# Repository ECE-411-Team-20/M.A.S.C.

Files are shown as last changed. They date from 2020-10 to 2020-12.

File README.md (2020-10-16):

# Project M.A.S.C.
Practicum Project

Mask to Actively Shield from COVID (M.A.S.C.)

A face shield of some type (either head or collar mounted) that exposes the face by default, but should the wearer start to walk, or should someone approach the user, the face shield moves to cover the wearer's face

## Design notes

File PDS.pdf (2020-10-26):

Welsh Jehnoy, Genther Derrick, Huynh Khoa, Arch Ryan, Yogi Saputra Team 20
ECE 411
10/25/2020
Homework 2 PDS

Executive Summary / Concept of Operations
Mask to Actively Shield from COVID (M.A.S.C.)
The MASC is an automated COVID facemask to optimize the users mask experience during COVID, and future, pandemics. Using cutting edge technology, this smart mask is capable to determining when the wearer is at the most risk of exposure to other persons due to proximity and automatically moves a barrier over the wearers face. When the risk has been determined to be mitigated by sufficient distance, the mask moves away from the wearers face.
As an additional precaution to protect the user in a chaotic world, the mask defaults to a closed position when the user walks for more than a few steps so that acute exposure can be prevented by quick moving persons during motion.

Brief Market Analysis
The MASC is designed to attract customers who want to only wear a mask when needed to avoid exposure to covid-19, or other airborne diseases. Certain persons such as nurses, and doctors will also be an intended target audience for the product as they will need it to make sure that they have worn a mask at the times when needed.
The competition is any products that help prevent exposure to covid-19. In particular, and the most common competition is any mask products as they are the most common item used to avoid exposure to covid-19 and other airborne illness. The mask product that will be produced has it’s advantage of automatically closing and opening based on it’s detection of possible airborne diseases nearby. This advantage will be used to take consumers who dislike wearing a mask when it’s not necessary to do so.
The price for this product will depend on the price of the parts needed to create the product. A strong price to keep the product competitive is $20. This will ensure that customers won’t be lured away from purchasing the product because of a large price tag, and it’ll be cheap enough to make a decent profit.

Requirements
The mask must be able to detect when it needs to close to prevent the user contracting any airborne diseases. The mask will be able to detect it based on the distance of the user to another human, in which the mask will close upon close proximity to someone else. The mask must close when the user is walking. The mask must open when nobody is near them. The mask must be a portable device that can fit on the user’s face. The mask must be as lightweight as possible and comfortable on the wearer’s head. The mask must allow the user to breathe.

System Architecture

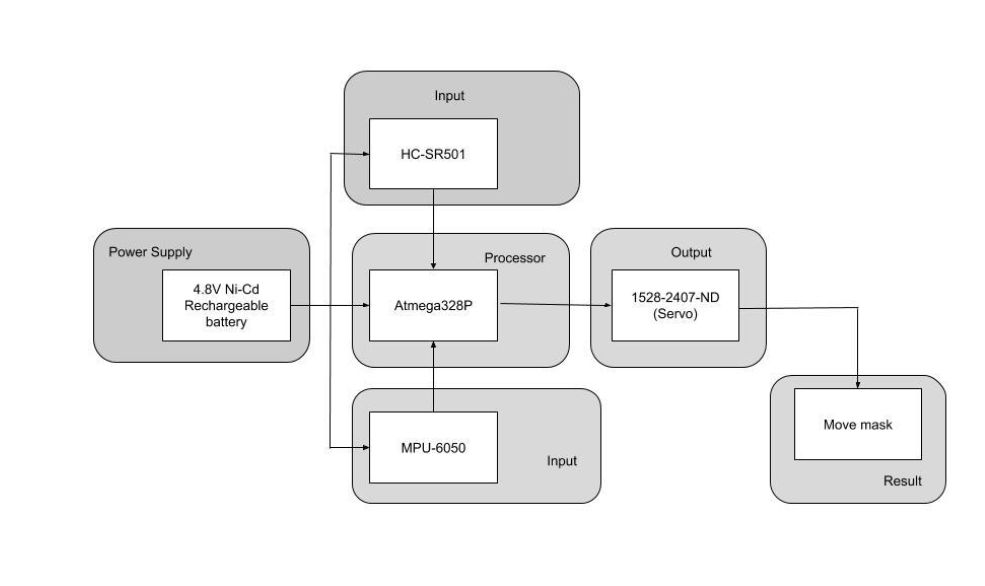
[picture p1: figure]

Design Specification
The unit will operate off of a Atmega328P that has been pre-loaded with the Arduino bootloader, which will be the IDE in the development.
This controller will utilize passive infrared detectors (HC-SR501) to tell if a person moves into proximity of the unit and an accelerometer (MPU-6050) to determine whether or not the wearer is in motion.
The sensors and microcontroller will be powered through a single 4.8V Ni-Cd rechargeable battery bank.
The motion of the shield itself is done through a continuous rotation servo (Adafruit PRODUCT ID: 3614) that is controlled via pulse-width modulation from the Atmega328P through an H-bridge circuit to be powered through a multi-cell battery pack (AA or C).
Prototyping will be done to determine the best means of motion for the mask. Types under consideration:
O Split mask than opens/closes in both directions
O Above-the-head mask that lowers/rises

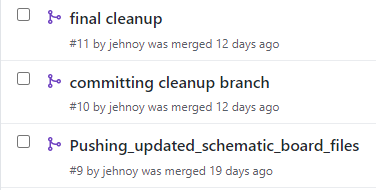
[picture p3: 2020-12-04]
final_commit_screenshots/Capture_commit.PNG

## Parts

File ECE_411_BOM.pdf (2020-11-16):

Bill of Materials for: Team 20 Last Modified: 11/12/2020
PCB version: design_v2
BOM revision: 1
Cnt | Parts | P/NP | Mfg | Mfg PN | Description | Dist | Dist Part Number | Cost Ea | Cost Total
1 | U1 | P | Atmel | ATMEGA328P-PU | 8-bit Microcontrollers - MCU 32KB In-system Flash 20MHz 1.8V-5.5V | Mouser | 556-ATMEGA328P-PU | $2.08 | $2.08
1 | Y1 | P | TXC Corp | 9B-16.000MEEJ-B | Crystals 16.000MHz 10ppm -20 +70C 18pF | Mouser | 717-9B-16.000MEEJ-B | $0.48 | $0.48
1 | J4 | P | Sparkfun | PRT-12748 | SparkFun Accessories DC Barrel Power Jack Connector SMD | Mouser | 474-PRT-12748 | $1.50 | $1.50
1 | IC1 | P | STMicroelectronics | LM317T | Linear Voltage Regulators 1.2-37V Adj Positive 1.5 Amp Output | Mouser | 511-LM317T | $0.64 | $0.64
2 | C7, C8 | P | TDK | C2012X5R1V106K0 85AC | Multilayer Ceramic Capacitors MLCC -SMD/SMT RECOMMENDED ALT 810-C2012X5R1V106K1C | Mouser | 810-C2012X5R1V106 K0C | $0.38 | $0.76
2 | C1, C2 | P | KEMET | C0805C220G5GAC TU | Multilayer Ceramic Capacitors MLCC -SMD/SMT 50V 22pF C0G 0805 0.02 | Mouser | 80-C0805C220G5G | $0.42 | $0.84
1 | C3 | P | KEMET | C0805X104M5RAC TU | Multilayer Ceramic Capacitors MLCC -SMD/SMT 50V 0.1uF X7R 0805 20% | Mouser | 80-C0805X104M5RAC TU | $0.52 | $0.52
1 | R2 | P | ROHM | SFR10EZPJ103 | Thick Film Resistors - SMD 10Kohm 0805 5% | Mouser | 755-SFR10EZPJ103 | $0.11 | $0.11
1 | S1 | P | C&K | PTS645SK50JSMT R92 LFS | Tactile Switches 50mA 12VDC, SPST NO, 260 gf, 5.0mm H, SMT J-type | Mouser | 611-SK50JSMTR92LF S | $0.41 | $0.41
1 | J1 | P | Adafruit | 1465 | ADAPTER MINI KIT BB AVR ISP 6PIN | Digi-Key | 1528-1189-ND | $0.95 | $0.95
1 | J2 | P | Wurth Electronik | 61300611121 | CONN HEADER VERT 6POS 2.54MM | Digi-Key | 732-5319-ND | $0.33 | $0.33

1 | M1 | N/P | Sparkfun | ROB-12625 | SparkFun Accessories Servo - Hitec HS-755HB (1/4 Scale) | Mouser | 474-ROB-12625 | $39.94 | $39.94
1 | U4 | N/P | MCM | 287-18001 | PIR motion detector module | Newark | 25AC5060 | $2.99 | $2.99
Total: | | | | | | | | $51.55

VERSION INFO

Rev | Date | Notes
1.0 | 2020-11-12 | Initial BOM.

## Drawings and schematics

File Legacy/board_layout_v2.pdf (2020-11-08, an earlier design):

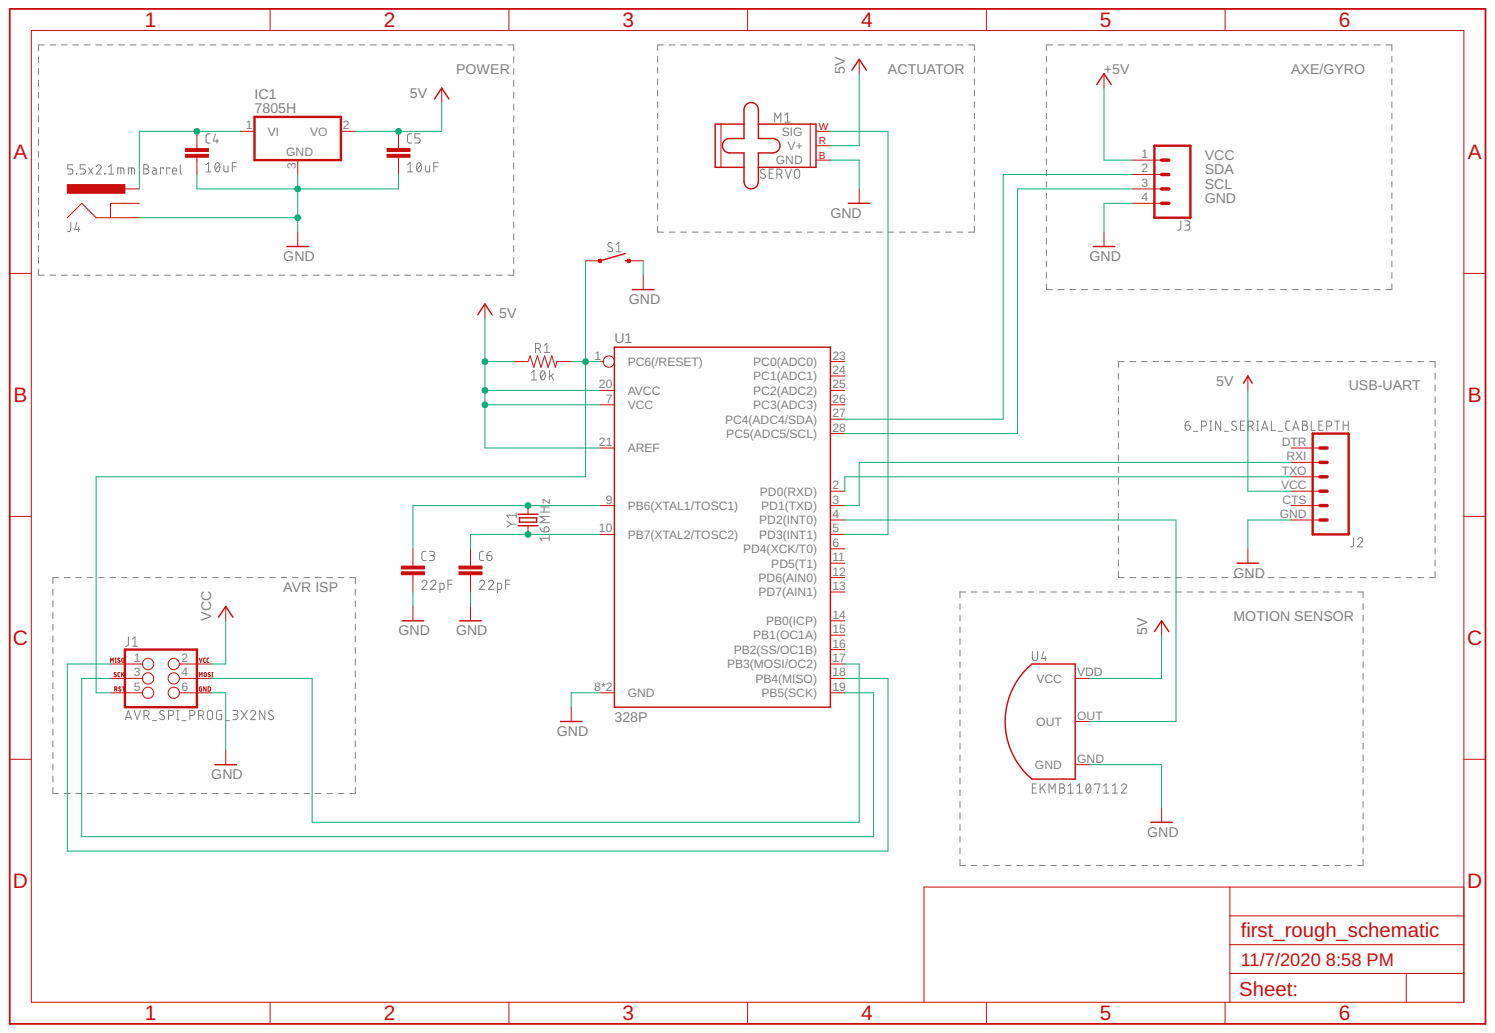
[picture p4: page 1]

3 4
5 6

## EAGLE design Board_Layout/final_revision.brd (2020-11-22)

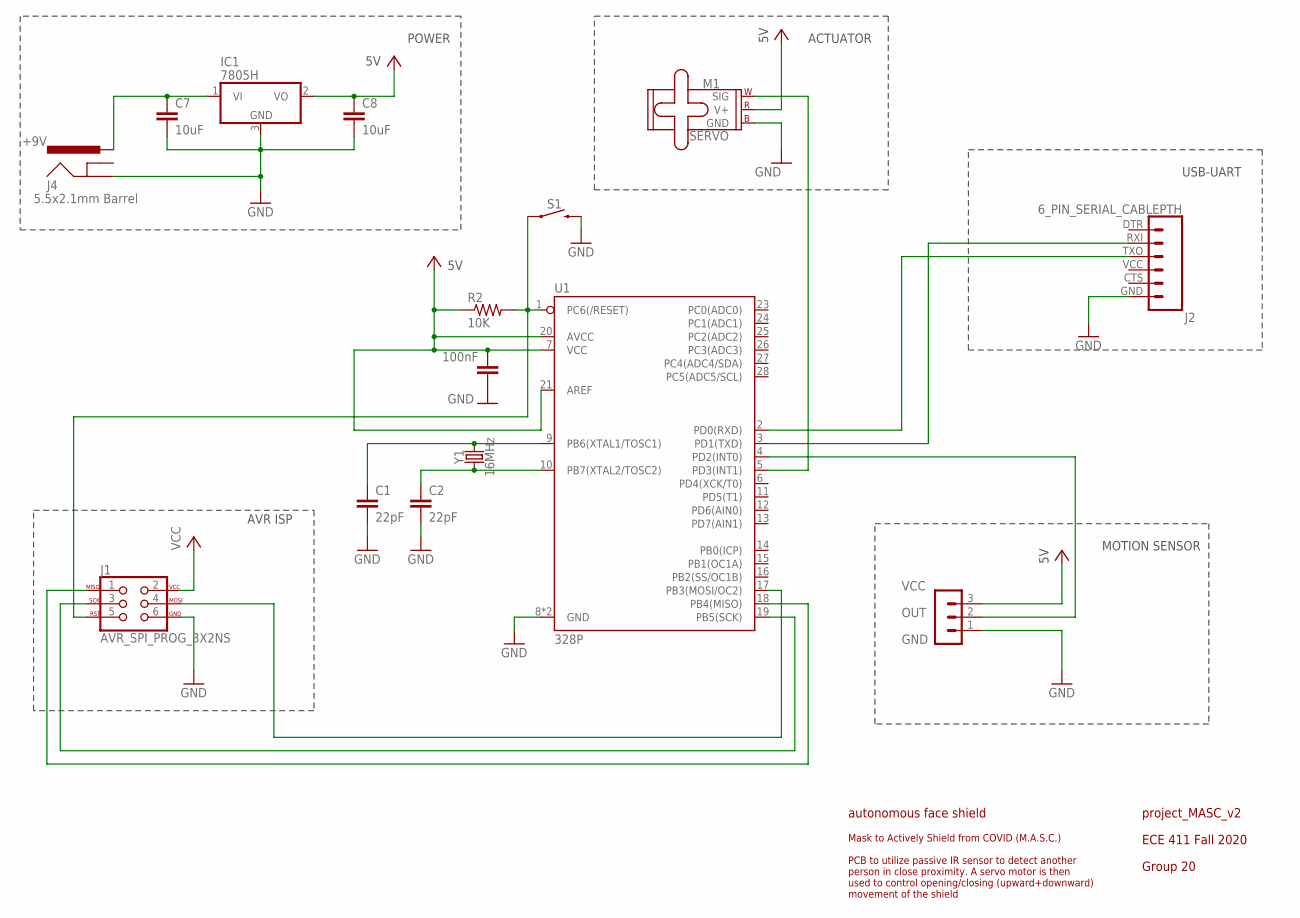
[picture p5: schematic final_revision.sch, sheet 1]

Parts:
C1, C2: 22pF; 0805
C3: 100nF; 0805
C7, C8: 10uF; 0805
IC1: 7805H; TO39
J1: AVR_SPI_PROG_3X2NS; 2X3-NS
J2: 6_PIN_SERIAL_CABLEPTH; FTDI_BASIC
J4: 5.5x2.1mm Barrel; POWER_JACK_SMD
M1: SERVO; 1X03
R2: 10K; R0805
S1: MOMENTARY-SWITCH-SPST-PTH-6.0MM; TACTILE_SWITCH_PTH_6.0MM
SV1: MA03-1
U1: 328P; DIP28
Y1: 16MHz; HC49US

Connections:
GND: C1.2, C2.2, C3.1, C7.2, C8.2, IC1.3 (GND), J1.6, J2.GND (6), J4.P$4 (GND), M1.3 (GND), S1.3 (2), SV1.1, U1.8 (GND), U1.22 (GND)
unnamed: J1.5, R2.2, S1.1, U1.1 (PC6(/RESET))
unnamed: J2.TXO (3), U1.2 (PD0(RXD))
unnamed: J2.RXI (2), U1.3 (PD1(TXD))
unnamed: C1.1, U1.9 (PB6(XTAL1/TOSC1)), Y1.2
unnamed: C2.1, U1.10 (PB7(XTAL2/TOSC2)), Y1.1
unnamed: C7.1, IC1.1 (VI), J4.VIN0 (PWR)
unnamed: SV1.2, U1.4 (PD2(INT0))
unnamed: M1.1 (SIG), U1.5 (PD3(INT1))
unnamed: J1.3, U1.19 (PB5(SCK))
unnamed: J1.1, U1.18 (PB4(MISO))
unnamed: J1.4, U1.17 (PB3(MOSI/OC2))
VCC: C3.2, C8.1, IC1.2 (VO), J1.2, M1.2 (V+), R2.1, SV1.3, U1.7 (VCC), U1.20 (AVCC), U1.21 (AREF)

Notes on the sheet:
POWER
ACTUATOR
MOTION SENSOR
USB-UART
AVR ISP
project_MASC_v2
autonomous face shield
Mask to Actively Shield from COVID (M.A.S.C.) PCB to utilize passive IR sensor to detect another person in close proximity. A servo motor is then used to control opening/closing (upward+downward) movement of the shield
Group 20
ECE 411 Fall 2020
+9V
VCC
OUT
GND

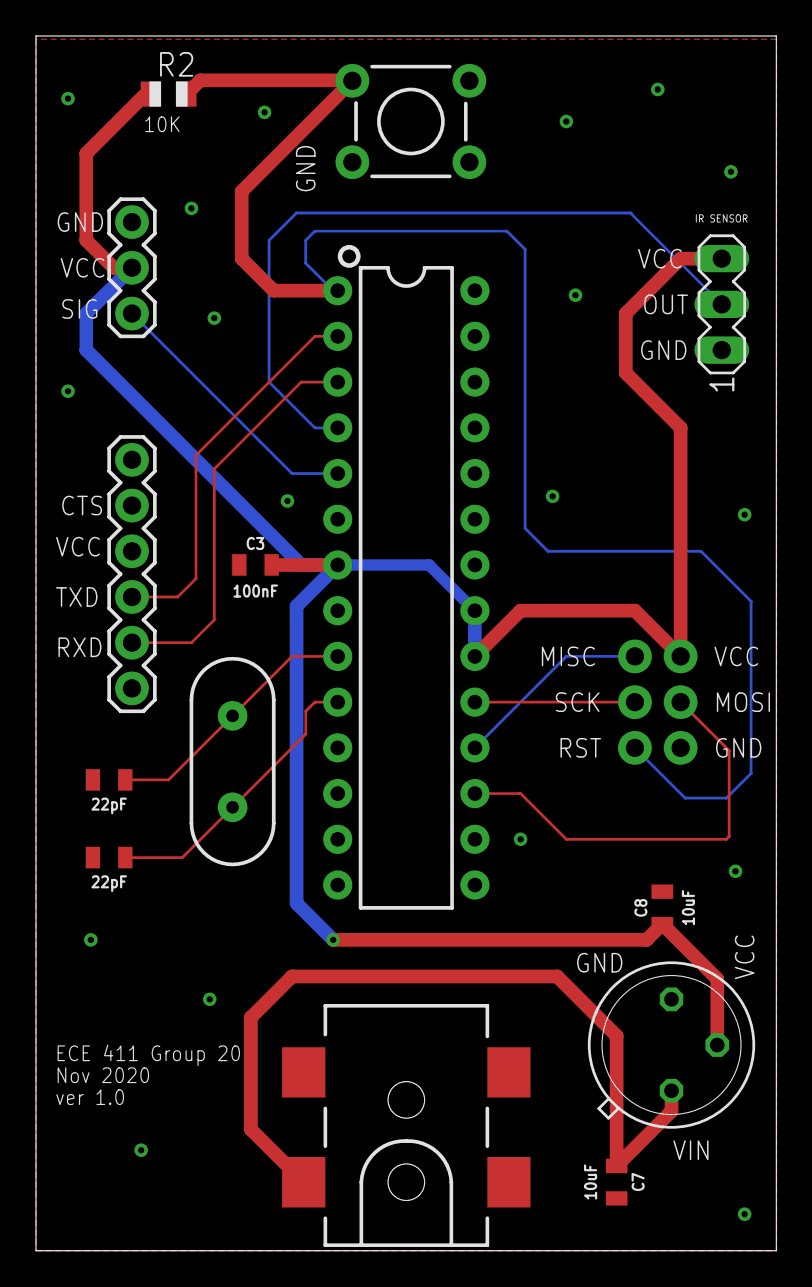
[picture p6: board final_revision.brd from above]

Board: 2 copper layers, 41.1 x 67.5 mm, 15 parts (0 on the bottom side), 13 nets.

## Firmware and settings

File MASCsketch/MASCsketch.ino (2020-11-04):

/*
M.A.S.C.

This program is designed to control an automated
mask.

-The mask must be able to detect when it needs to 
  close to prevent the user contracting any airborne 
  diseases. 
-The mask will be able to detect it based on the 
  distance of the user to another human, in which 
  the mask will close upon close proximity to 
  someone else. 
-The mask must close when the user is walking. 
  The mask must open when nobody is near them. 
-The mask must be a portable device that can 
  fit on the user’s face. 
-The mask must be as lightweight as possible 
  and comfortable on the wearer’s head. 
-The mask must allow the user to breathe.


*Requirements aboveSpecified
If a heat signature moves within 3 meters of the user,
the mask will close.

If we sense motion over a certain amount that 
might indicate walking movement, the mask will close.

If no one is around AND acceleration in X or Y direction 
is under () meters per second squared, the mask will open.
*/

#include "Wire.h"     // I2C communication library

//Passive InfraRed Motion Sensor Pin
#define sensorPin 18      // package pin4 PD2(INT0) PCINT18

//Servo Actuator Pin
#define servoPin 19       // package pin5 PD3(INT1) PCINT19 PWM

const int MPU_ADDR = 0x68;    //I2C address of the MPU-6050 Accelerometer


/*
//Don't really need all of them,
//just displaying register addresses for reference

//MPU-6050 registers for Accelerometer
const int ACCEL_XOUT_H = 0x3B;
const int ACCEL_XOUT_L = 0x3C;
const int ACCEL_YOUT_H = 0x3D;
const int ACCEL_YOUT_L = 0x3E;
const int ACCEL_ZOUT_H = 0x3F;
const int ACCEL_ZOUT_L = 0x40;

//MPU-6050 registers for temperature sensor
const int TEMP_OUT_H = 0x41;
const int TEMP_OUT_L = 0x42;

//MPU-6050 registers for Gyroscope
const int GYRO_XOUT_H = 0x43;
const int GYRO_XOUT_L = 0x44;
const int GYRO_YOUT_H = 0x45;
const int GYRO_YOUT_L = 0x46;
const int GYRO_ZOUT_H = 0x47;
const int GYRO_ZOUT_L = 0x48;
*/

//16 bit integers for sensor values
int16_t accel_x;
int16_t accel_y;
int16_t accel_z;
int16_t temperature;
int16_t gyro_x;
int16_t gyro_y;
int16_t gyro_z;

void setup() {
  Serial.begin(9600);
  Wire.begin();
  Wire.beginTransmission(MPU_ADDR);   //begins transmission to 
  Wire.write(0x6B);     // PWR_MGMT_1 register
  Wire.write(0);        // set CLKSEL to 0 which turns on internal 8MHz oscillator
  Wire.endTransmission(true); 
}

void loop() {
  
  Wire.beginTransmission(MPU_ADDR);
  
  Wire.write(ACCEL_XOUT_H);             // This is the first register in the data registers, 
                                        // we begin reading here                                   
  Wire.endTransmission(false);          // sends restart message to MPU-6050 and keeps connection open
  
  Wire.requestFrom(MPU_ADDR, 14, true); // request data from 14 byte registers and send stop message.

  //read in all data from MPU-6050
  accel_x = Wire.read()<<8 | Wire.read();   //reads ACCEL_XOUT_H and ACCEL_XOUT_L registers
  accel_y = Wire.read()<<8 | Wire.read();   //reads ACCEL_YOUT_H and ACCEL_YOUT_L registers
  accel_z = Wire.read()<<8 | Wire.read();   //reads ACCEL_ZOUT_H and ACCEL_ZOUT_L registers
  temperature = Wire.read()<<8 | Wire.read();   //reads TEMP_OUT_H and TEMP_OUT_L registers
  gyro_x = Wire.read()<<8 | Wire.read();    //reads GYRO_ZOUT_H and GYRO_ZOUT_L registers
  gyro_y = Wire.read()<<8 | Wire.read();    //reads GYRO_ZOUT_H and GYRO_ZOUT_L registers
  gyro_z = Wire.read()<<8 | Wire.read();    //reads GYRO_ZOUT_H and GYRO_ZOUT_L registers
  
  //print to console all data from MPU-6050
  Serial.print("Accelerometer (X, Y, Z) = (");
  Serial.print(accel_x); Serial.print(", ");
  Serial.print(accel_y); Serial.print(", ");
  Serial.print(accel_z); Serial.println(")");

  Serial.print("Gyroscope (X, Y, Z) = (");
  Serial.print(gyro_x); Serial.print(", ");
  Serial.print(gyro_y); Serial.print(", ");
  Serial.print(gyro_z); Serial.println(")");

  Serial.print("Temperature = ");
  Serial.println(temperature);
  Serial.println();
}

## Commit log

2020-11-01 Adding first schematic drafts
    [first_rough_schematic.sch]
2020-11-02 Uploading breadboard prototype files
2020-11-04 Added MASC Arduino sketch WIP
    So far I've only added the ability to read the acceleromter/gyroscope into memory.
    Still need:
    -Read Passive InfraRed Sensor, store in memory.
    -Create logic structure which checks acceleration and infrared motion.
    -Control Servo based on input.
    Pins were based off the ATMega328P Pinout Mapping that I've also posted on Git.
2020-11-08 Revised schematic and board layout
    Made changes to schematic
    Made changes to board layout to include a barrel jack connector
    [board_layout_v2.brd, board_schematic_v2.sch]
2020-11-08 Adding snapshots of board
2020-11-22 committing cleanup branch
    [board_schematic_v2.brd, board_schematic_v2.sch, design_v2.brd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]
2020-11-22 final cleanup
    [board_layout_v2.brd, board_schematic_v2.sch, design_v2.brd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]

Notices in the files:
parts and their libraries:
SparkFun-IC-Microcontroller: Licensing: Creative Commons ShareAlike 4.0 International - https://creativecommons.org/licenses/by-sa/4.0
